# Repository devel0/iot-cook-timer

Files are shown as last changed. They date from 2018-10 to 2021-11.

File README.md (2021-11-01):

# iot-cook-timer

minutes, seconds timeout cook timer

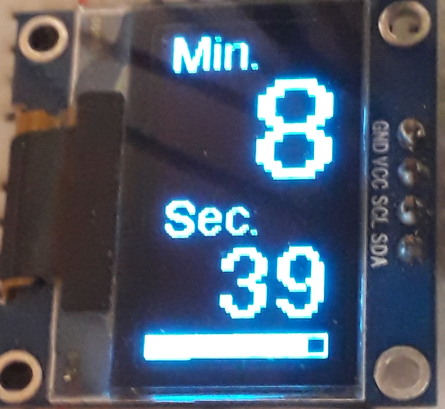
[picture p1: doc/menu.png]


<!-- TOC -->
* [features](#features)
* [dev env](#dev-env)
* [hardware](#hardware)
* [connections](#connections)
* [3d print](#3d-print)
* [power management circuit](#power-management-circuit)
  + [qucs](#qucs)
  + [circuitjs](#circuitjs)
<!-- TOCEND -->

## features

- set minutes, seconds add with push buttons
- countdown with progressbar
- key tones
- time expire audibile 10 sec sound
- standby power <0.00uA
- active power 18mA
- battery LiOn 3.7V power source
- autoshutdown after 10 sec

## dev env

- [vscode arduino](https://github.com/devel0/knowledge/blob/master/doc/vscode-arduino.md)
- arduino libraries ( available through Library Manager )
  - [OneWire](https://www.pjrc.com/teensy/td_libs_OneWire.html)
  - [Adafruit SSD1306](https://github.com/adafruit/Adafruit_SSD1306)
  - [Adafruit GFX](https://github.com/adafruit/Adafruit-GFX-Library)
  - [arduino-utils](https://github.com/devel0/iot-arduino-utils)

## hardware

- atmega328p
- oled ssd1306 128x64 two wire interface
- piezo buzzer

## connections

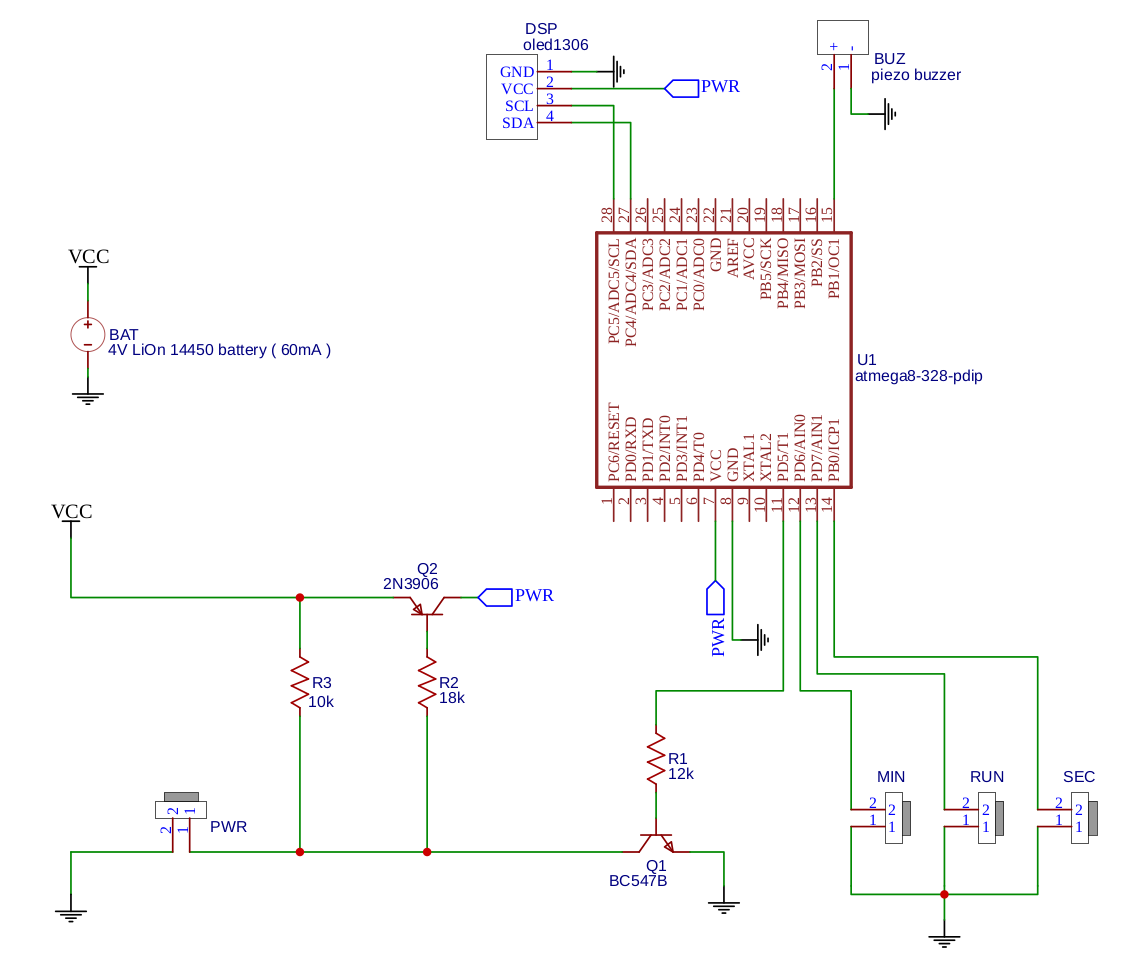
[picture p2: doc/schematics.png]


- [schematics and pcb](https://easyeda.com/editor#id=|7909cea401894073bcae4e8e6450cbe7|0390ee86049a4889954c34540dc8de61) also available ready to print [pcb](doc/pcb.pdf) [labels](doc/pcb-labels.pdf)
- power on
  - push button ( replace T0/T2 in schematics below ) ; this required for power on cycle
- atmega328p
  - `GND`
  - `VCC` from load power management circuit (see below)
  - `SCL SDA` to oled
  - digital pin 9 to piezo (+)
  - `TX` to serial `RX` (optional)
  - digital pin 5 to NPN transistor base ( replace T1/T3 in schematics below ) ; this required to maintain PNP transistor active until auto shutdown
  - digital pin 6 ( MINUTES ADD ) to push button pulled down with R10K to GND
  - digital pin 7 ( SECONDS ADD ) to push button pulled down with R10K to GND
  - digital pin 8 ( START COUNTDOWN ) to push button pulled down with R10K to GND
- serial (optional)
  - `GND`
- piezo
  - `GND`
- oled
  - `GND`
  - `VCC` from load power management circuit (see below)  

## 3d print

- 3d print pieces [front](doc/front.stl) [lateral](doc/tri.stl) with freecad [src](doc/box.fcstd)

## power management circuit

### qucs

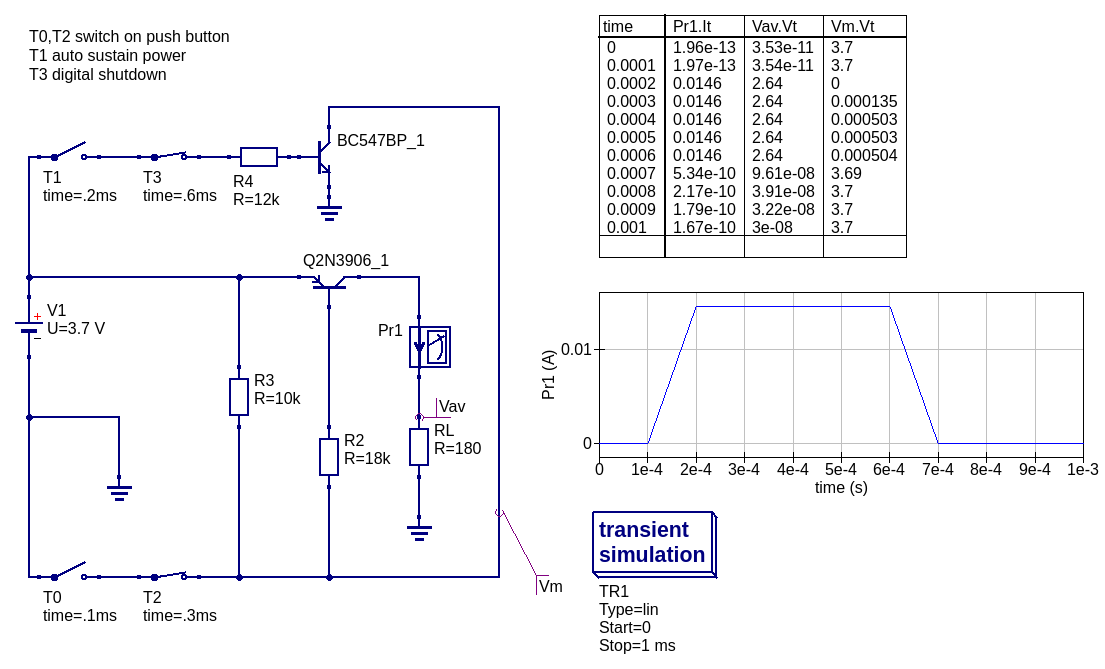
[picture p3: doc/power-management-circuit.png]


- [qucs simulation](doc/prj.sch)
- T0,T2 describe power on switch in a transient way ( T0 switches to close after 0.1ms enabling power while T2 switches to open after 0.3ms simulating push button release )
- T1,T3 describe digital pin 5 that maintains system on until pin goes low disabling main transistor Q2N3906
- RL represents atmega+oled consumption
- R3 is a pullup resistor to avoid Q2N main transistor draw a little current 0.3uA when system powered off
- graph shown power on switch (T0T2) at 1e-4s ; system autosustain (T1T3) at 2e-4 where Vm near 0mV ; power on switch release at 3e-4 with no effect due to BC547 activated transistor ; shutdown at 6e-4 by toggling T3 ( digital pin 5 low )

### circuitjs

- see [online](http://lushprojects.com/circuitjs/circuitjs.html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)

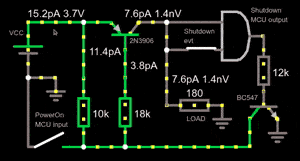
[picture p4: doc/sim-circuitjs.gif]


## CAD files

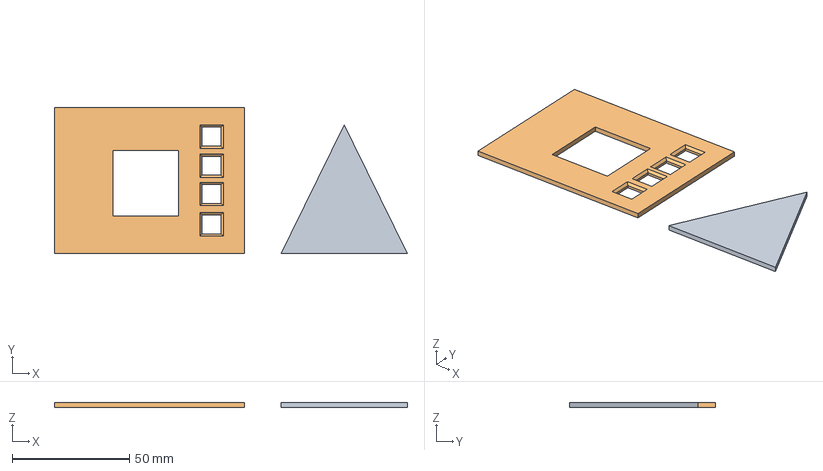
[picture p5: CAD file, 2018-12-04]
doc/box.fcstd
150.6 x 62.5 x 2.00 mm

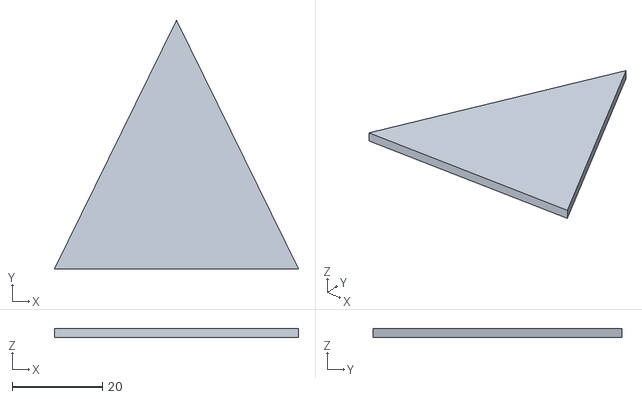
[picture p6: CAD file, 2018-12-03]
doc/tri.stl
54.0 x 55.0 x 2.00

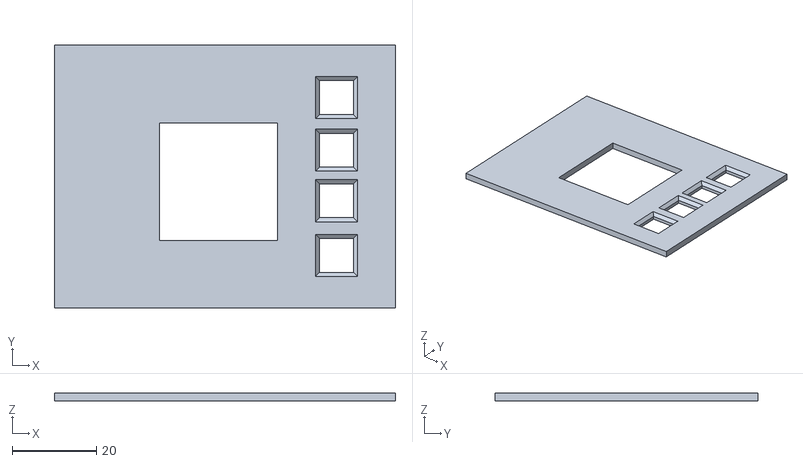
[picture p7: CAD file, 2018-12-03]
doc/front.stl
81.0 x 62.5 x 2.00

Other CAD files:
doc/box.dxf

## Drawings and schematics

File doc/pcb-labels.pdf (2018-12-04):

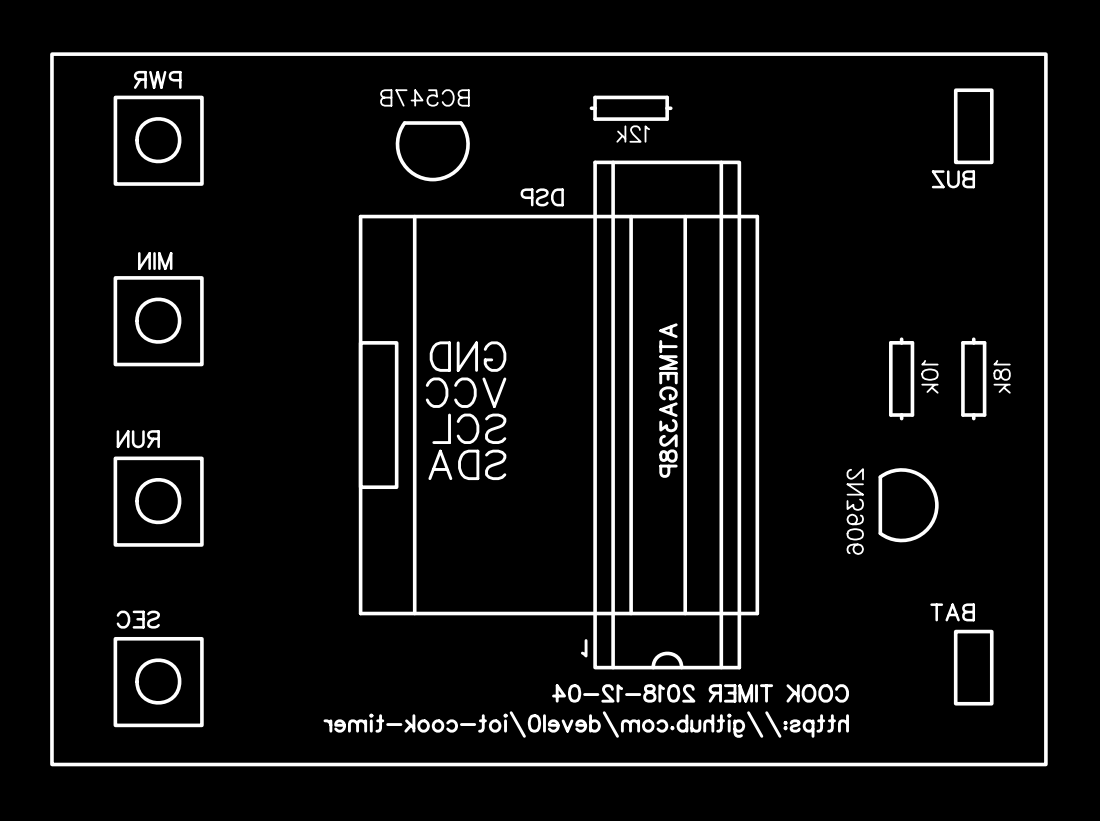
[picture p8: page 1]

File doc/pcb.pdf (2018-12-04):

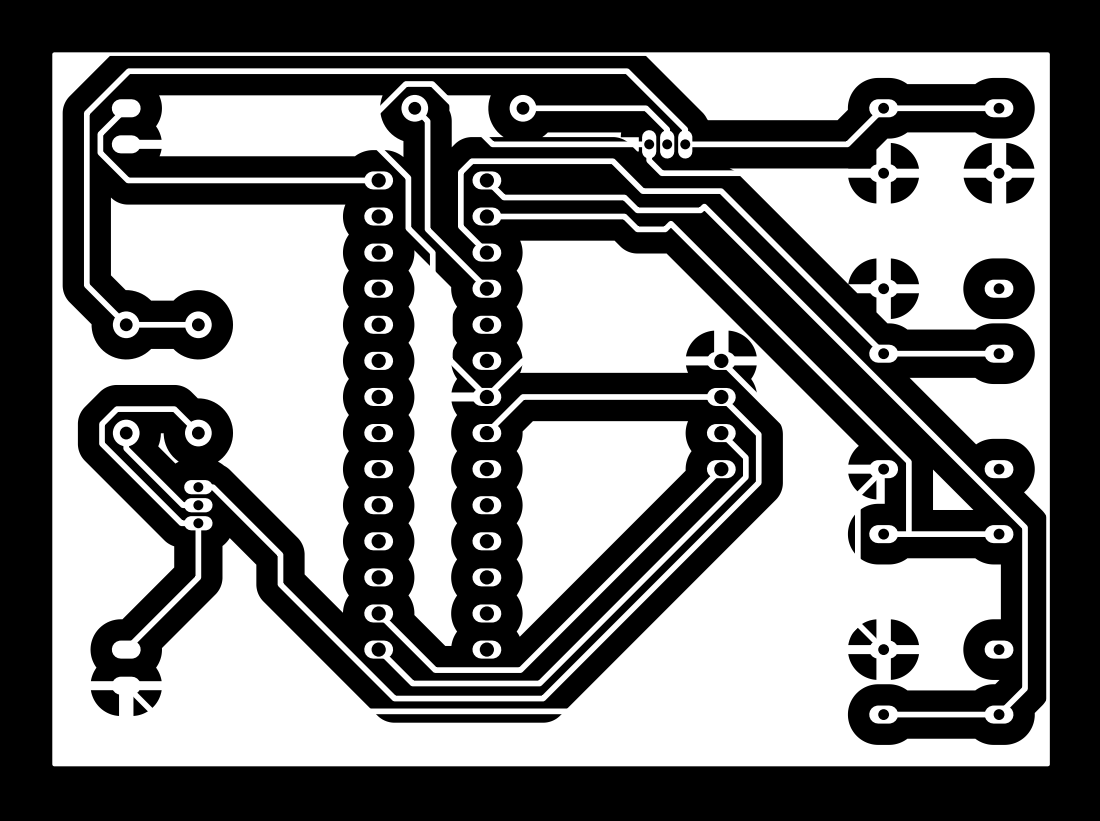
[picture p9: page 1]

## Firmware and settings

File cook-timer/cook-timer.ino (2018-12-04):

#define SERIAL_DEBUG
#define SERIAL_SPEED 57600
#define TR_PIN 5
#define MIN_PIN 6
#define SEC_PIN 8
#define START_PIN 7
#define BUZ_PIN 9
#define AUTOPOWEROFF_TIMEOUT_SEC 10

// set to 0 in release
#define TEST_BUZ 0

#include <SPI.h>
#include <Wire.h>
#include <Adafruit_GFX.h>
#include <Adafruit_SSD1306.h>
#include <Fonts/FreeSans9pt7b.h>

// EDIT DebugMacros to set SERIAL_SPEED and enable/disable DPRINT_SERIAL
#include <DPrint.h>
#include <Util.h>
using namespace SearchAThing::Arduino;

#ifndef SSD1306_128_64
#error "set display on Adafruit_SSD1306.h"
#endif

#define OLED_RESET 4
Adafruit_SSD1306 display(OLED_RESET);

void TR_HIGH()
{
  digitalWrite(TR_PIN, HIGH);
}

void TR_LOW()
{
  digitalWrite(TR_PIN, LOW);
}

void shutdown()
{
  TR_LOW();
}

void beep()
{
  tone(BUZ_PIN, 1500, 5);
}

void beep2()
{
  tone(BUZ_PIN, 2000, 50);
}

void drawTime(int mm, int ss, int progress)
{
  display.clearDisplay();

  display.setTextSize(1);
  display.setCursor(4, 13);
  display.print("Min.");

  if (mm > 0)
  {
    display.setTextSize(3);
    display.setCursor(4, 56);
    if (mm < 10)
    {
      display.setTextColor(BLACK);
      display.print('0');
      display.setTextColor(WHITE);
    }
    display.print(mm);
  }

  display.setTextSize(1);
  display.setCursor(4, 80);
  display.print("Sec.");

  if (ss > 0)
  {
    display.setTextSize(2);
    display.setCursor(24, 111);
    if (ss < 10)
    {
      display.setTextColor(BLACK);
      display.print('0');
      display.setTextColor(WHITE);
    }
    display.print(ss);
  }

  display.fillRect(0, 120, 63 * progress / 100, 127, WHITE);
  display.drawLine(0, 120, 63, 120, WHITE);
  display.drawLine(0, 127, 63, 127, WHITE);
  display.drawLine(63, 120, 63, 127, WHITE);
  display.display();
}

/*-----------*/
/* VARIABLES */
/*-----------*/

int mm = 0;
int ss = 0;
int progress = 100;

#define STATE_IDLE 0
#define STATE_STARTED 1
#define STATE_TIMEOUT 2

#define TIMEOUT_BEEP_SEC 15

int state = STATE_IDLE;
long int start_time = 0;
long int timeout_start_time = 0;
long int last_activity_time = 0;

/*-----------*/
/* SETUP     */
/*-----------*/

void setup()
{
  pinMode(TR_PIN, OUTPUT);
  TR_HIGH();

  pinMode(MIN_PIN, INPUT_PULLUP);
  pinMode(SEC_PIN, INPUT_PULLUP);
  pinMode(START_PIN, INPUT_PULLUP);

  pinMode(BUZ_PIN, OUTPUT);

  display.begin(SSD1306_SWITCHCAPVCC, 0x3C);
  //display.begin(SSD1306_EXTERNALVCC, 0x3C);

  display.setRotation(3);

  display.setTextColor(WHITE);
  display.setFont(&FreeSans9pt7b);

  DPrintStr("display width = ");
  DPrintInt16ln(display.width());
  DPrintStr("display height = ");
  DPrintInt16ln(display.height());
  last_activity_time = millis();
}

/*-----------*/
/* LOOP      */
/*-----------*/

// return false if expired
bool drawElapsed()
{
  int totsec = 60 * mm + ss;
  int totsec_elapsed = TimeDiff(start_time, millis()) / 1000;
  int totsec_diff = totsec - totsec_elapsed;
  if (totsec_elapsed < totsec)
  {
    int mm_diff = totsec_diff / 60;
    int ss_diff = totsec_diff - (60 * mm_diff);

    drawTime(mm_diff, ss_diff, 100 - totsec_elapsed * 100 / totsec);

    return true;
  }
  else
    return false;
}

volatile bool min_pressed = false, sec_pressed = false, start_pressed = false;

int tone_test = 440;

int min_press_cnt = 0;
unsigned long min_press_accepted_timestamp; // uninitialized until min_press_cnt==0

void loop()
{
  sec_pressed = digitalRead(SEC_PIN) == LOW;
  min_pressed = digitalRead(MIN_PIN) == LOW;
  start_pressed = digitalRead(START_PIN) == LOW;

  if (state == STATE_IDLE && (TimeDiff(last_activity_time, millis()) / 1000 > AUTOPOWEROFF_TIMEOUT_SEC))
  {
    beep();
    shutdown();
  }

  if (min_pressed || sec_pressed || start_pressed)
  {
    last_activity_time = millis();
  }

  if (!min_pressed)
    min_press_cnt = 0;

  // reset
  if (
      (min_pressed && sec_pressed) ||
      (min_pressed && start_pressed) ||
      (start_pressed && sec_pressed) ||
      (state == STATE_TIMEOUT && (min_pressed || sec_pressed || start_pressed)))
  {
    mm = ss = 0;
    progress = 100;
    drawTime(mm, ss, progress);
    state = STATE_IDLE;
    beep2();
    delay(500);
    return;
  }
  else if (min_pressed)
  {
    if (
        min_press_cnt == 0 ||
        (min_press_cnt == 1 && TimeDiff(min_press_accepted_timestamp, millis()) > 500) ||
        (min_press_cnt > 1 && TimeDiff(min_press_accepted_timestamp, millis()) > 50))
    {
      min_press_accepted_timestamp = millis();
      ++min_press_cnt;
      beep();
      ++mm;
      if (mm > 60)
        mm = 0;
    }
  }
  else if (sec_pressed)
  {
    beep();
    ++ss;
    if (ss > 60)
      ss = 0;
  }
  else if (start_pressed)
  {
    beep2();
    if (state == STATE_STARTED)
    {
      state = STATE_IDLE;
      delay(500);
    }
    else
    {
      start_time = millis();
      state = STATE_STARTED;
    }
    delay(500);
  }

  if (state == STATE_STARTED)
  {
    if (!drawElapsed())
    {
      state = STATE_TIMEOUT;
      last_activity_time = timeout_start_time = millis();
      drawTime(mm, ss, progress);
    }
  }
  else
    drawTime(mm, ss, progress);

  if (state == STATE_TIMEOUT)
  {
    if (TimeDiff(timeout_start_time, millis()) < TIMEOUT_BEEP_SEC * 1000)
    {
      for (int i = 0; i < 4; ++i)
      {
        tone(BUZ_PIN, 1000, 40);
        delay(100);
      }
      delay(500);
    }
    else
    {
      state = STATE_IDLE;
    }
  }
}

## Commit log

2018-12-03 adjusted finish buzzer tone ; deactivate timeout prematurely by pressing any key
    [cook-timer.ino]
2018-12-03 allow stop by either min+sec or start+min or start+sec ; adjusted pin for new pcb
2018-12-03 pcb and 3d print pieces
    [back.stl, box.dxf, box.fcstd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]
2018-12-04 code cleanup ; setup min button to run slow at first hit
2018-12-04 dxf outside box labels
    [box.dxf]
2018-12-04 removed push button not needed pulldown resistor
2018-12-04 removed back cover
    [back.stl, box.dxf, box.fcstd]
2021-03-08 remove unsupported SimInhibitWindow ; should use forked version for this https://github.com/SearchAThing-forks/qucs
    [prj.sch]
2021-11-01 circuitjs sim
